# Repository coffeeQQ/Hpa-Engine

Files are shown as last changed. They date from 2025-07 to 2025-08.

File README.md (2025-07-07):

# Hpa-Engine

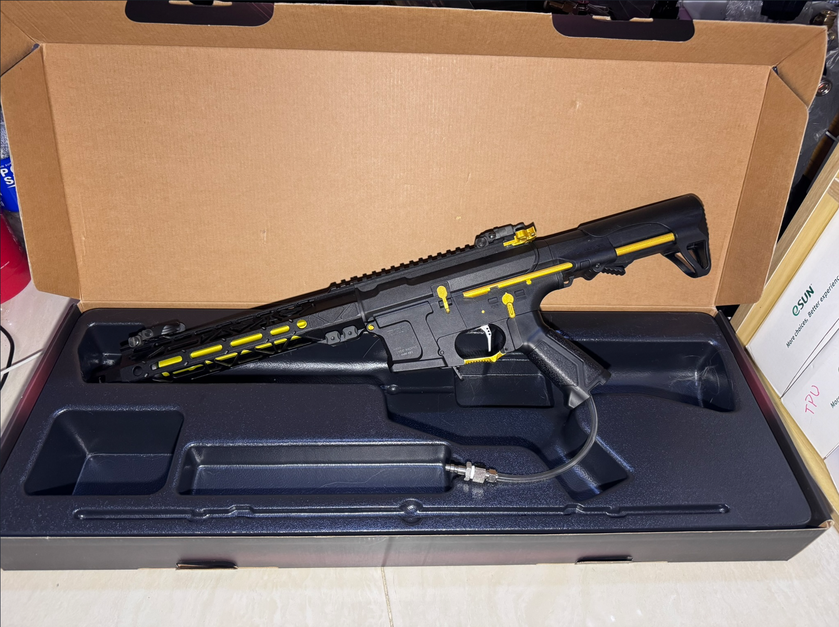
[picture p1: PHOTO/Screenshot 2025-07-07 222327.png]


需要準備以下材料
-
控制板部分

Esp32 Super mini x1

IRLB8743 x1

SB560 x1 

10歐電阻x1

10k歐電阻x1

XH2.54 4Pin90度插座x1

XH2.54 2Pin90度插座x1

洞洞板x1

24awg導線2m
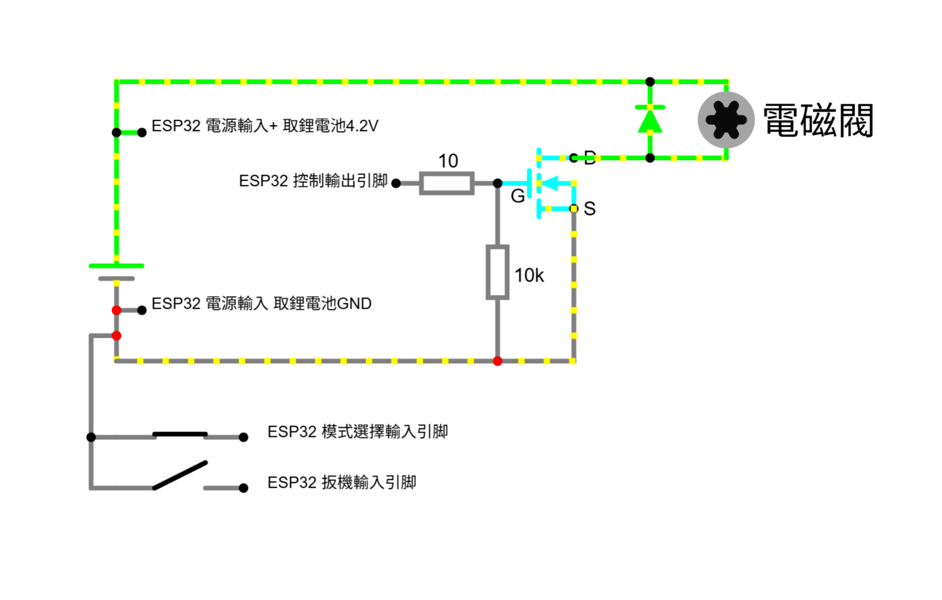
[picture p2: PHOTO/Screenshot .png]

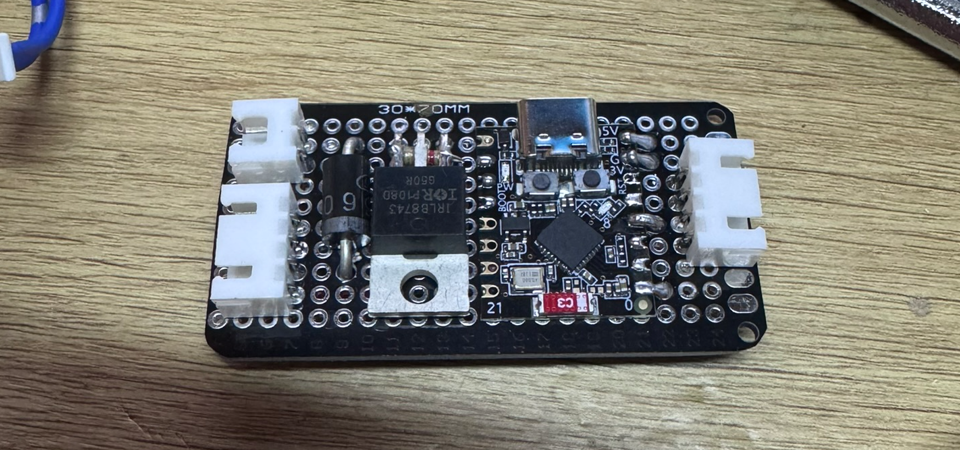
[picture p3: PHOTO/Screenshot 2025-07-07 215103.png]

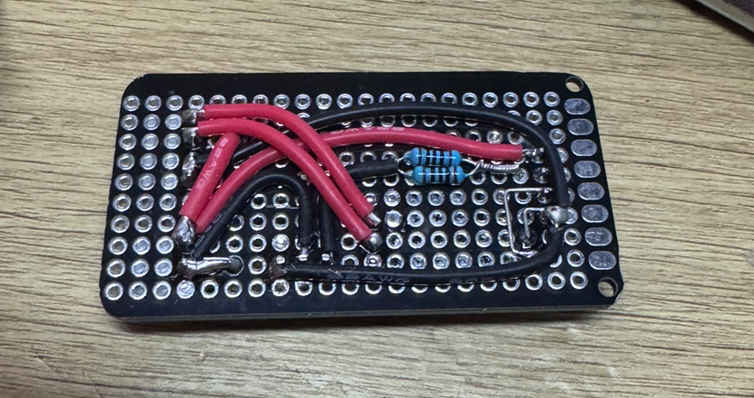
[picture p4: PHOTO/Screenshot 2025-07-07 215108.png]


-

波箱部分

12v氣喇叭電磁閥x1 或其它電磁閥代替

NPT1/8-6mmPU管快接 x1 根據電磁閥選擇

NPT1/4-6mmPu管快接 x1 根據電磁閥選擇

BPT1/4-6mmPu管快接 x1

6mmPu管1m

美規快插頭x1

無拉橋套件 x1

24x2.4 Oring x2

波箱我直接使用G&G班機組 可以使用兩個微動開關並使用m2螺絲固定於波殼上代替
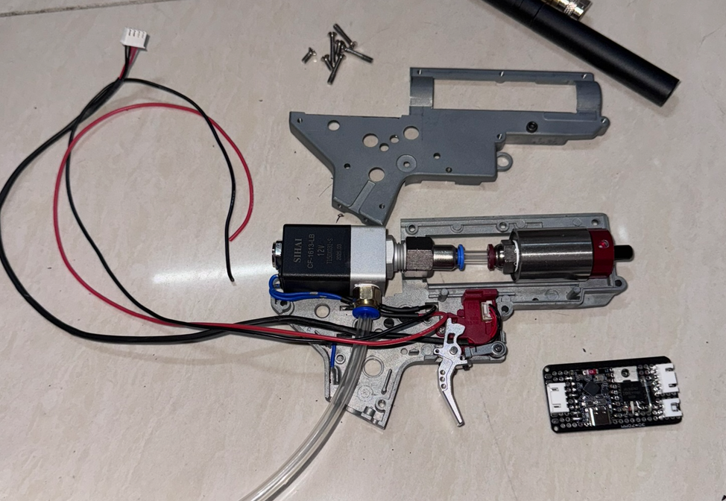
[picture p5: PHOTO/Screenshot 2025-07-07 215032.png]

-

工具,其他部分

需要打磨很多槍身部位，和使用一顆M5螺絲固定後托
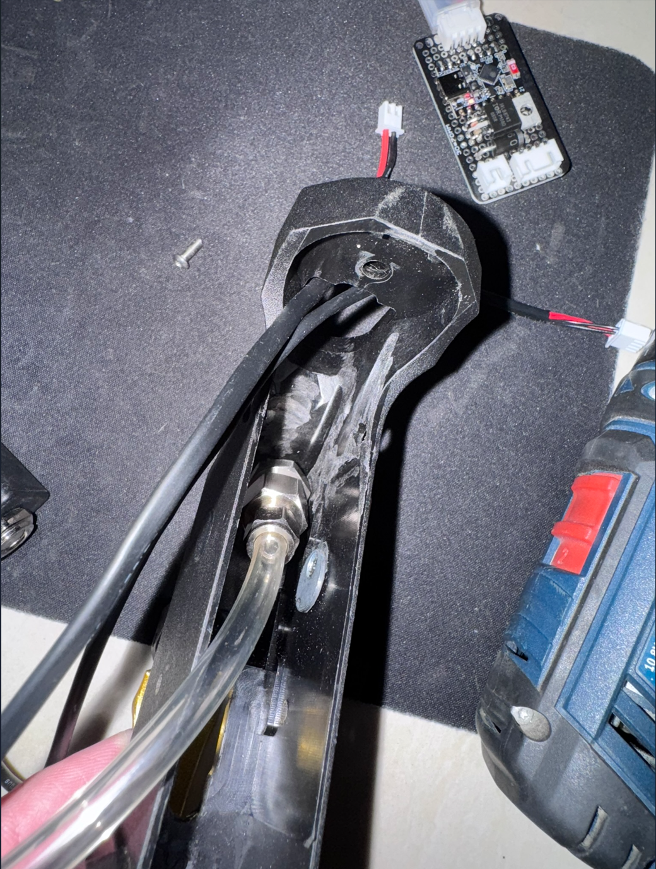
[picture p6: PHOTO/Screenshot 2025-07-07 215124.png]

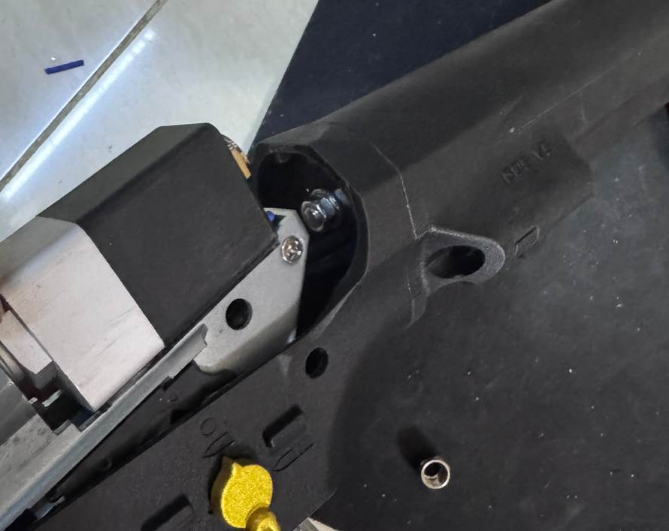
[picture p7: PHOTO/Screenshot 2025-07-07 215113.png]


鋸子 銼刀 螺絲刀 鉗子 端子鉗 烙鐵 錫線 絲錐BPT1/4 （用於攻3D打印件牙）

一雙手 腦子 
大瓶裝可樂！！！！
大瓶裝可樂！！！！
大瓶裝可樂！！！！

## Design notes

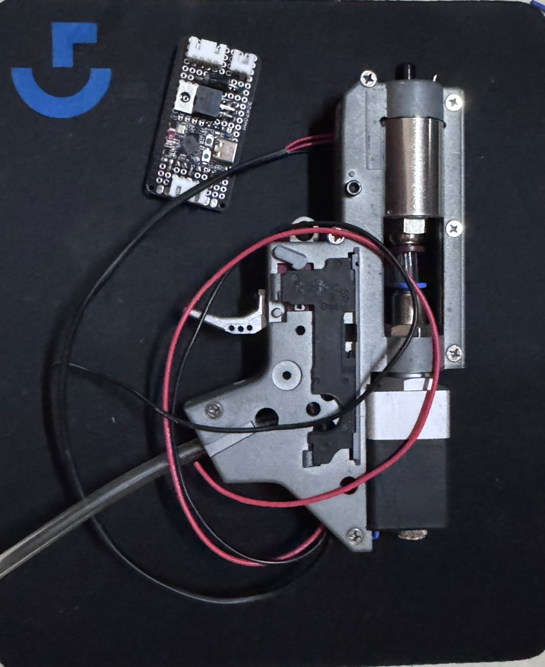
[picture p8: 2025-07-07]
PHOTO/Screenshot 2025-07-07 215045.png

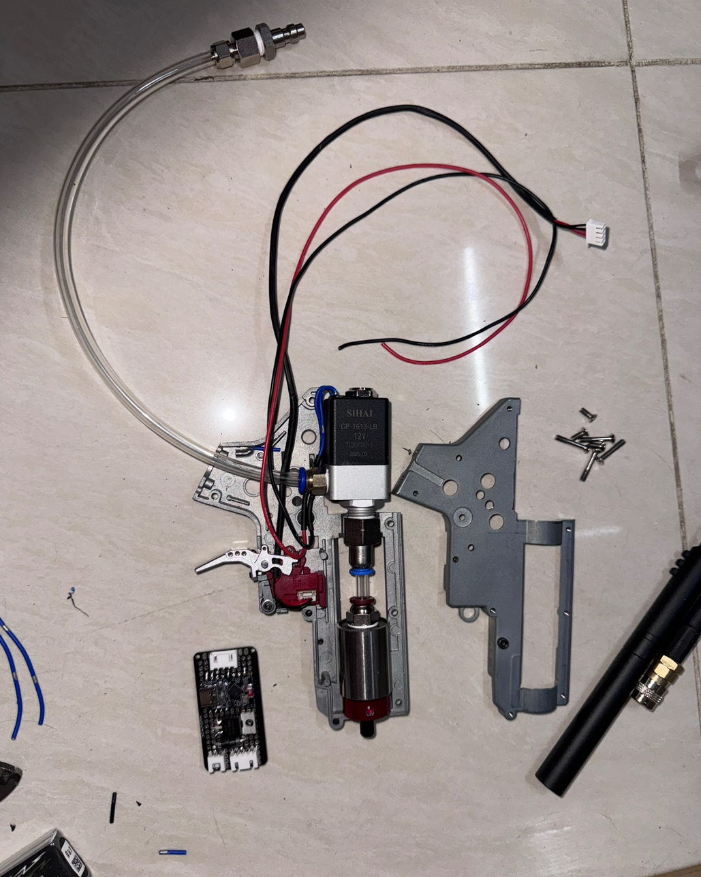
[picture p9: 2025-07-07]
PHOTO/Screenshot 2025-07-07 215019.png

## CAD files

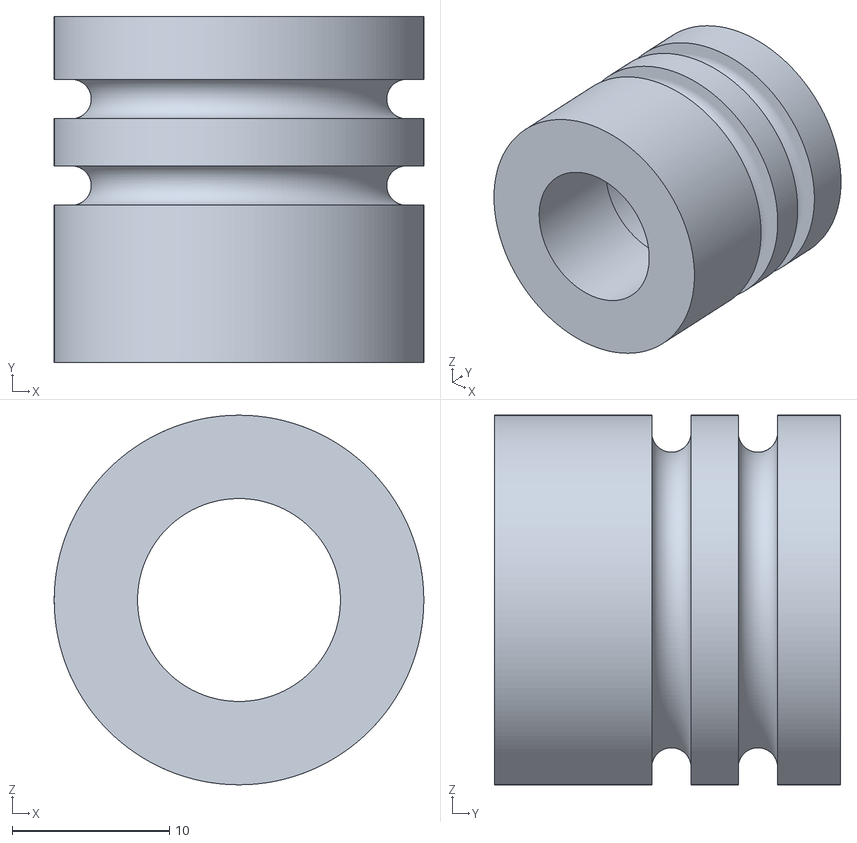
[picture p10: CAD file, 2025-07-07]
hpa.stl
23.5 x 22.0 x 23.5

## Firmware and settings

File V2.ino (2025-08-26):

#include <Arduino.h>
#include <WiFi.h>
#include <WebServer.h>
#include <Preferences.h>

// 硬體引腳定義
#define SOLENOID_PIN 10
#define MODE_PIN 9
#define TRIGGER_PIN 20
#define WIFI_LED_PIN 8  // 新增WiFi狀態指示燈

// 參數變量
int DWELL_TIME = 10;
int ROF_DELAY = 20;
int BURST_COUNT = 3;
int BURST_INTERVAL = 70;

// 射擊模式
enum FireMode {
  MODE_SINGLE,
  MODE_FULL_AUTO,
  MODE_DOUBLE_ACTION,
  MODE_CUSTOM_BURST
};

FireMode singlePosMode = MODE_SINGLE;
FireMode autoPosMode = MODE_FULL_AUTO;

// WiFi设置
const char* ssid = "COFFEE.HPA.FCU";  // 預設AP名稱
const char* password = "12345678";    // 預設AP密碼
const char* knownSSIDs[] = {"COFFEE.HPA.FCU", "A", "B"};  // 已知WiFi列表
const char* knownPasswords[] = {"12345678", "00001111", "00000000"};  // 對應密碼
WebServer server(80);

// 使用Preferences替代原始EEPROM
Preferences prefs;

// 函數前置聲明
void handleRoot();
void handleSetParams();
void handleSave();
void handleReset();
void loadSettings();
void saveSettings();
void singleShot();
void fullAutoMode();
void doubleAction();
void customBurst();
void connectToWiFi();  // 新增WiFi連接函數
void startAPMode();    // 新增AP模式啟動函數
void blinkWiFiLED(int times, int delayTime);  // 新增LED指示函數

void setup() {
  Serial.begin(115200);
  
  // 初始化引腳
  pinMode(TRIGGER_PIN, INPUT_PULLUP);
  pinMode(SOLENOID_PIN, OUTPUT);
  pinMode(MODE_PIN, INPUT_PULLUP);
  pinMode(WIFI_LED_PIN, OUTPUT);
  digitalWrite(SOLENOID_PIN, LOW);
  
  // 初始化 Preferences
  if (!prefs.begin("hpa-settings", false)) {
    Serial.println("Failed to initialize preferences");
  } else {
    Serial.println("Preferences initialized successfully");
  }
  
  // 加載設置
  loadSettings();
  
  // 嘗試連接已知WiFi
  connectToWiFi();
  
  // 設定Web伺服器
  server.on("/", HTTP_GET, handleRoot);
  server.on("/setparams", HTTP_POST, handleSetParams);
  server.on("/save", HTTP_GET, handleSave);
  server.on("/reset", HTTP_GET, handleReset);
  
  server.begin();
  Serial.println("HTTP server started");
}

void loop() {
  server.handleClient();
  
  if (!digitalRead(TRIGGER_PIN)) {
    if (!digitalRead(MODE_PIN)) {
      // 連發位置模式
      switch(autoPosMode) {
        case MODE_SINGLE: singleShot(); break;
        case MODE_FULL_AUTO: fullAutoMode(); break;
        case MODE_DOUBLE_ACTION: doubleAction(); break;
        case MODE_CUSTOM_BURST: customBurst(); break;
      }
    } else {
      // 單發位置模式
      switch(singlePosMode) {
        case MODE_SINGLE: singleShot(); break;
        case MODE_FULL_AUTO: fullAutoMode(); break;
        case MODE_DOUBLE_ACTION: doubleAction(); break;
        case MODE_CUSTOM_BURST: customBurst(); break;
      }
    }
  } else {
    digitalWrite(SOLENOID_PIN, LOW);
  }
}

// 新增WiFi連接函數
void connectToWiFi() {
  Serial.println("Scanning for known WiFi networks...");
  
  // 先掃描附近網路
  WiFi.mode(WIFI_STA);
  WiFi.disconnect();
  delay(100);
  
  int n = WiFi.scanNetworks();
  if (n == 0) {
    Serial.println("No networks found");
    WiFi.scanDelete();  // 釋放掃描結果記憶體
    startAPMode();
    return;
  }
  
  // 檢查已知網路是否存在
  bool foundKnownNetwork = false;
  for (int i = 0; i < sizeof(knownSSIDs)/sizeof(knownSSIDs[0]); i++) {
    for (int j = 0; j < n; j++) {
      if (strcmp(knownSSIDs[i], WiFi.SSID(j).c_str()) == 0) {
        foundKnownNetwork = true;
        Serial.print("Found known network: ");
        Serial.println(knownSSIDs[i]);
        
        // 嘗試連接
        WiFi.begin(knownSSIDs[i], knownPasswords[i]);
        Serial.print("Connecting to WiFi ");
        Serial.println(knownSSIDs[i]);
        
        int attempts = 0;
        while (WiFi.status() != WL_CONNECTED && attempts < 20) {  // 嘗試20次
          delay(500);
          Serial.print(".");
          digitalWrite(WIFI_LED_PIN, !digitalRead(WIFI_LED_PIN));  // 閃爍表示正在連接
          attempts++;
        }
        
        if (WiFi.status() == WL_CONNECTED) {
          Serial.println("\nConnected!");
          Serial.print("IP Address: ");
          Serial.println(WiFi.localIP());
          digitalWrite(WIFI_LED_PIN, HIGH);  // 常亮表示已連接
          WiFi.scanDelete();  // 釋放掃描結果記憶體
          return;
        } else {
          Serial.println("\nFailed to connect");
          WiFi.disconnect();  // 斷開連接
          blinkWiFiLED(5, 200);  // 快速閃爍5次表示連接失敗
        }
      }
    }
  }
  
  WiFi.scanDelete();  // 釋放掃描結果記憶體
  
  if (!foundKnownNetwork) {
    Serial.println("No known networks found");
  }
  
  // 如果沒有找到已知網路或連接失敗，啟動AP模式
  Serial.println("Starting AP mode");
  startAPMode();
}

// 改進後的AP模式啟動函數
void startAPMode() {
  WiFi.mode(WIFI_AP);
  WiFi.softAP(ssid, password);
  Serial.println("WiFi AP started");
  Serial.print("AP SSID: ");
  Serial.println(ssid);
  Serial.print("IP Address: ");
  Serial.println(WiFi.softAPIP());
  
  // AP模式下LED慢閃
  while (true) {
    digitalWrite(WIFI_LED_PIN, LOW);
    delay(500);
    digitalWrite(WIFI_LED_PIN, HIGH);
    delay(1500);
    
    // 定期嘗試重新連接
    static unsigned long lastTryTime = 0;
    if (millis() - lastTryTime > 30000) {  // 每30秒嘗試一次
      lastTryTime = millis();
      Serial.println("Attempting to reconnect...");
      connectToWiFi();
      if (WiFi.status() == WL_CONNECTED) {
        break;  // 如果連接成功，退出AP模式
      }
    }
    
    server.handleClient();  // 處理Web請求
  }
}
// 新增LED指示函數
void blinkWiFiLED(int times, int delayTime) {
  for (int i = 0; i < times; i++) {
    digitalWrite(WIFI_LED_PIN, LOW);
    delay(delayTime);
    digitalWrite(WIFI_LED_PIN, HIGH);
    delay(delayTime);
  }
}

// 模塊
void singleShot() {
  digitalWrite(SOLENOID_PIN, HIGH);
  delay(DWELL_TIME);
  digitalWrite(SOLENOID_PIN, LOW);
  while (!digitalRead(TRIGGER_PIN)) {}
  delay(50);
}

void fullAutoMode() {
  digitalWrite(SOLENOID_PIN, HIGH);
  delay(DWELL_TIME);
  digitalWrite(SOLENOID_PIN, LOW);
  delay(ROF_DELAY);
}

void doubleAction() {
  digitalWrite(SOLENOID_PIN, HIGH);
  delay(DWELL_TIME);
  digitalWrite(SOLENOID_PIN, LOW);
  while (!digitalRead(TRIGGER_PIN)) {}
  delay(50);
  digitalWrite(SOLENOID_PIN, HIGH);
  delay(DWELL_TIME);
  digitalWrite(SOLENOID_PIN, LOW);
  delay(100);
}

void customBurst() {
  for (int i = 0; i < BURST_COUNT; i++) {
    digitalWrite(SOLENOID_PIN, HIGH);
    delay(DWELL_TIME);
    digitalWrite(SOLENOID_PIN, LOW);
    if (i < BURST_COUNT - 1) delay(BURST_INTERVAL);
  }
  while (!digitalRead(TRIGGER_PIN)) {}
  delay(50);
}

// 設定管理
void loadSettings() {
  Serial.println("Loading settings from preferences...");
  prefs.begin("hpa-settings", true);
  
  DWELL_TIME = prefs.getInt("dwell", 10);
  ROF_DELAY = prefs.getInt("rof", 20);
  BURST_COUNT = prefs.getInt("burst", 3);
  BURST_INTERVAL = prefs.getInt("interval", 100);
  singlePosMode = (FireMode)prefs.getUChar("single", MODE_SINGLE);
  autoPosMode = (FireMode)prefs.getUChar("auto", MODE_FULL_AUTO);
  
  // 驗證參數範圍
  if(DWELL_TIME < 1 || DWELL_TIME > 100) DWELL_TIME = 10;
  if(ROF_DELAY < 1 || ROF_DELAY > 500) ROF_DELAY = 20;
  if(BURST_COUNT < 1 || BURST_COUNT > 10) BURST_COUNT = 3;
  if(BURST_INTERVAL < 1 || BURST_INTERVAL > 1000) BURST_INTERVAL = 100;
  if(singlePosMode > MODE_CUSTOM_BURST) singlePosMode = MODE_SINGLE;
  if(autoPosMode > MODE_CUSTOM_BURST) autoPosMode = MODE_FULL_AUTO;
  
  Serial.printf("Loaded settings: dwell=%d, rof=%d, burst=%d, interval=%d, singleMode=%d, autoMode=%d\n",
               DWELL_TIME, ROF_DELAY, BURST_COUNT, BURST_INTERVAL, singlePosMode, autoPosMode);
  
  prefs.end();
}

void saveSettings() {
  Serial.println("Saving settings to preferences...");
  prefs.begin("hpa-settings", false);
  
  prefs.putInt("dwell", DWELL_TIME);
  prefs.putInt("rof", ROF_DELAY);
  prefs.putInt("burst", BURST_COUNT);
  prefs.putInt("interval", BURST_INTERVAL);
  prefs.putUChar("single", (uint8_t)singlePosMode);
  prefs.putUChar("auto", (uint8_t)autoPosMode);
  
  Serial.printf("Saved settings: dwell=%d, rof=%d, burst=%d, interval=%d, singleMode=%d, autoMode=%d\n",
               DWELL_TIME, ROF_DELAY, BURST_COUNT, BURST_INTERVAL, singlePosMode, autoPosMode);
  
  prefs.end();
}

void handleReset() {
  Serial.println("Resetting to default settings...");
  DWELL_TIME = 10;
  ROF_DELAY = 20;
  BURST_COUNT = 3;
  BURST_INTERVAL = 70;
  singlePosMode = MODE_SINGLE;
  autoPosMode = MODE_FULL_AUTO;
  
  saveSettings();
  
  String html = "<script>alert('已恢復預設設定！');window.location='/';</script>";
  server.send(200, "text/html", html);
}

// Web介面處理
void handleRoot() {
  String html = R"=====(
<!DOCTYPE html>
<html>
<head>
  <title>HPA CONTROL</title>
  <meta charset="UTF-8">
  <meta name="viewport" content="width=device-width, initial-scale=1">
  <style>
    body { font-family: Arial, sans-serif; background-color: #333; color: #eee; margin: 0; padding: 20px; }
    .container { max-width: 600px; margin: 0 auto; }
    h1 { color: #ff9800; text-align: center; }
    .mode-section { background-color: #444; padding: 15px; border-radius: 8px; margin-bottom: 20px; }
    h2 { color: #ff9800; margin-top: 0; }
    .btn-group { display: flex; flex-wrap: wrap; gap: 10px; margin-bottom: 10px; }
    .btn { background-color: #ff9800; color: #333; border: none; padding: 10px 15px; 
           border-radius: 4px; cursor: pointer; font-weight: bold; flex: 1; min-width: 100px; text-align: center; }
    .btn.active { background-color: #ff5722; color: white; }
    .param-form { background-color: #444; padding: 15px; border-radius: 8px; margin-bottom: 20px; }
    .param-group { margin-bottom: 15px; }
    label { display: block; margin-bottom: 5px; color: #ff9800; }
    .slider { width: 100%; height: 15px; border-radius: 5px; background: #555; outline: none; -webkit-appearance: none; }
    .slider::-webkit-slider-thumb { -webkit-appearance: none; width: 25px; height: 25px; border-radius: 50%; background: #ff9800; cursor: pointer; }
    .value-display { display: inline-block; width: 50px; text-align: right; }
    .save-area { display: flex; gap: 10px; }
    .save-btn { background-color: #4caf50; color: white; border: none; padding: 12px; border-radius: 4px; cursor: pointer; flex: 1; }
    .reset-btn { background-color: #f44336; color: white; border: none; padding: 12px; border-radius: 4px; cursor: pointer; flex: 1; }
    .toast { position: fixed; bottom: 20px; right: 20px; background-color: #4CAF50; color: white; 
             padding: 10px; border-radius: 4px; z-index: 1000; display: none; }
  </style>
</head>
<body>
<div class="container">
  <h1>HPA CONTROL</h1>
  
  <div class="mode-section">
    <h2>單發位置模式</h2>
    <div class="btn-group" id="single_pos_btn_group">
      <button class="btn" onclick="setMode('single_pos','single')" id="single_pos_single" data-mode="single">單發模式</button>
      <button class="btn" onclick="setMode('single_pos','auto')" id="single_pos_auto" data-mode="auto">連發模式</button>
      <button class="btn" onclick="setMode('single_pos','double')" id="single_pos_double" data-mode="double">雙向扳機</button>
      <button class="btn" onclick="setMode('single_pos','burst')" id="single_pos_burst" data-mode="burst">自定義連發</button>
    </div>
  </div>
  
  <div class="mode-section">
    <h2>連發位置模式</h2>
    <div class="btn-group" id="auto_pos_btn_group">
      <button class="btn" onclick="setMode('auto_pos','single')" id="auto_pos_single" data-mode="single">單發模式</button>
      <button class="btn" onclick="setMode('auto_pos','auto')" id="auto_pos_auto" data-mode="auto">連發模式</button>
      <button class="btn" onclick="setMode('auto_pos','double')" id="auto_pos_double" data-mode="double">雙向扳機</button>
      <button class="btn" onclick="setMode('auto_pos','burst')" id="auto_pos_burst" data-mode="burst">自定義連發</button>
    </div>
  </div>
  
  <div class="param-form">
    <h2>參數設定</h2>
    <div class="param-group">
      <label for="dwell">電磁閥開啟時間: <span class="value-display" id="dwell_value">)=====";
  html += DWELL_TIME;
  html += R"=====(</span> ms</label>
      <input type="range" id="dwell" min="1" max="50" value=")=====";
  html += DWELL_TIME;
  html += R"=====(" class="slider">
    </div>
    <div class="param-group">
      <label for="rof">連發射速控制: <span class="value-display" id="rof_value">)=====";
  html += ROF_DELAY;
  html += R"=====(</span> ms</label>
      <input type="range" id="rof" min="1" max="150" value=")=====";
  html += ROF_DELAY;
  html += R"=====(" class="slider">
    </div>
    <div class="param-group">
      <label>預測射速: <span class="value-display" id="rps_value">)=====";
  float rps = 1000.0 / (DWELL_TIME + ROF_DELAY);
  html += String(rps, 1);
  html += R"=====(</span> RPS</label>
    </div>
    <div class="param-group">
      <label for="burst_count">自定義連發次數: <span class="value-display" id="burst_count_value">)=====";
  html += BURST_COUNT;
  html += R"=====(</span> 發</label>
      <input type="range" id="burst_count" min="1" max="15" value=")=====";
  html += BURST_COUNT;
  html += R"=====(" class="slider">
    </div>
    <div class="param-group">
      <label for="burst_interval">自定義連發間隔: <span class="value-display" id="burst_interval_value">)=====";
  html += BURST_INTERVAL;
  html += R"=====(</span> ms</label>
      <input type="range" id="burst_interval" min="1" max="300" value=")=====";
  html += BURST_INTERVAL;
  html += R"=====(" class="slider">
    </div>
    
    <div class="save-area">
      <button class="save-btn" onclick="saveSettings()">儲存設定</button>
      <button class="reset-btn" onclick="resetSettings()">恢復預設</button>
    </div>
  </div>
</div>

<div class="toast" id="toast"></div>

<script>
// 初始化按鈕狀態
document.addEventListener('DOMContentLoaded', function() {
  updateButtonStates();
  updateRPS();
});

// 滑動條事件監聽
document.querySelectorAll('.slider').forEach(slider => {
  document.getElementById(slider.id + "_value").textContent = slider.value;
  slider.addEventListener('input', function() {
    document.getElementById(this.id + "_value").textContent = this.value;
    updateRPS();
  });
});

// 更新按鈕狀態
function updateButtonStates() {
  const singleMode = ")=====";
  html += (singlePosMode == MODE_SINGLE) ? "single" : 
          (singlePosMode == MODE_FULL_AUTO) ? "auto" :
          (singlePosMode == MODE_DOUBLE_ACTION) ? "double" : "burst";
  html += R"=====(";
  const autoMode = ")=====";
  html += (autoPosMode == MODE_SINGLE) ? "single" : 
          (autoPosMode == MODE_FULL_AUTO) ? "auto" :
          (autoPosMode == MODE_DOUBLE_ACTION) ? "double" : "burst";
  html += R"=====(";
  
  document.querySelectorAll('#single_pos_btn_group .btn').forEach(btn => {
    btn.classList.toggle('active', btn.dataset.mode === singleMode);
  });
  
  document.querySelectorAll('#auto_pos_btn_group .btn').forEach(btn => {
    btn.classList.toggle('active', btn.dataset.mode === autoMode);
  });
}

// RPS計算
function updateRPS() {
  const dwell = parseInt(document.getElementById('dwell').value);
  const rof = parseInt(document.getElementById('rof').value);
  const rps = 1000 / (dwell + rof);
  document.getElementById('rps_value').textContent = rps.toFixed(1);
}

// 設定模式
function setMode(position, mode) {
  const btnGroup = document.getElementById(position + '_btn_group');
  btnGroup.querySelectorAll('.btn').forEach(btn => {
    btn.classList.remove('active');
  });
  document.getElementById(`${position}_${mode}`).classList.add('active');
}

// 儲存設定
function saveSettings() {
  const singleMode = document.querySelector('#single_pos_btn_group .btn.active').dataset.mode;
  const autoMode = document.querySelector('#auto_pos_btn_group .btn.active').dataset.mode;
  
  const params = new URLSearchParams();
  params.append('single', singleMode);
  params.append('auto', autoMode);
  params.append('dwell', document.getElementById('dwell').value);
  params.append('rof', document.getElementById('rof').value);
  params.append('burst_count', document.getElementById('burst_count').value);
  params.append('burst_interval', document.getElementById('burst_interval').value);

  fetch('/setparams', {
    method: 'POST',
    body: params
  }).then(response => response.text())
    .then(text => {
      showToast(text);
      console.log(text);
    })
    .catch(err => {
      showToast('保存失敗');
      console.error(err);
    });
}

// 重置设置
function resetSettings() {
  if(confirm('確定要恢復預設設定嗎？')) {
    fetch('/reset').then(response => response.text())
      .then(text => {
        showToast(text);
        setTimeout(() => location.reload(), 1000);
      })
      .catch(err => {
        showToast('重置失敗');
        console.error(err);
      });
  }
}

// 顯示提示
function showToast(message) {
  const toast = document.getElementById('toast');
  toast.textContent = message;
  toast.style.display = 'block';
  setTimeout(() => toast.style.display = 'none', 2000);
}
</script>
</body>
</html>
)=====";

  server.send(200, "text/html; charset=utf-8", html);
}

void handleSetParams() {
  if (server.hasArg("single") && server.hasArg("auto") &&
      server.hasArg("dwell") && server.hasArg("rof") && 
      server.hasArg("burst_count") && server.hasArg("burst_interval")) {
      
    // 處理模式選擇
    String singleMode = server.arg("single");
    if (singleMode == "single") singlePosMode = MODE_SINGLE;
    else if (singleMode == "auto") singlePosMode = MODE_FULL_AUTO;
    else if (singleMode == "double") singlePosMode = MODE_DOUBLE_ACTION;
    else if (singleMode == "burst") singlePosMode = MODE_CUSTOM_BURST;

    String autoMode = server.arg("auto");
    if (autoMode == "single") autoPosMode = MODE_SINGLE;
    else if (autoMode == "auto") autoPosMode = MODE_FULL_AUTO;
    else if (autoMode == "double") autoPosMode = MODE_DOUBLE_ACTION;
    else if (autoMode == "burst") autoPosMode = MODE_CUSTOM_BURST;

    // 更新參數
    DWELL_TIME = server.arg("dwell").toInt();
    ROF_DELAY = server.arg("rof").toInt();
    BURST_COUNT = server.arg("burst_count").toInt();
    BURST_INTERVAL = server.arg("burst_interval").toInt();

    // 保存到Preferences
    saveSettings();
    
    server.send(200, "text/plain", "搞撚掂！");
  } else {
    server.send(400, "text/plain", "缺少參數");
  }
}

void handleSave() {
  handleSetParams(); // 直接呼叫相同的處理邏輯
}

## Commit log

2025-07-06 更新 README.md
2025-08-26 Add files via upload
    新增自动连接wifi功能
